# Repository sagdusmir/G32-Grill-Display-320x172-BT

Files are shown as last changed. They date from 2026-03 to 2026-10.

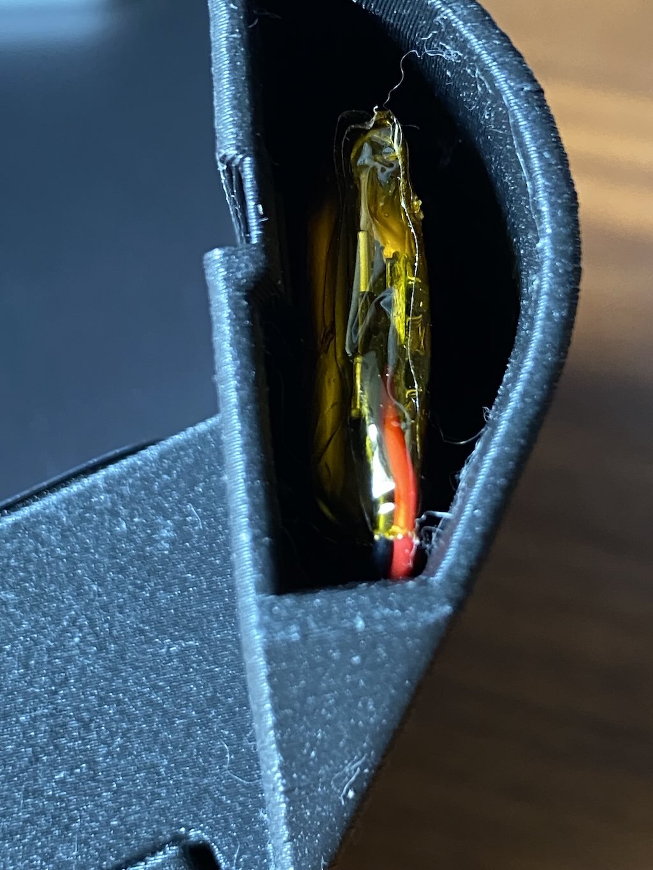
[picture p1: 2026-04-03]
misc/assembly/assembly_1_install_the_battery.jpeg

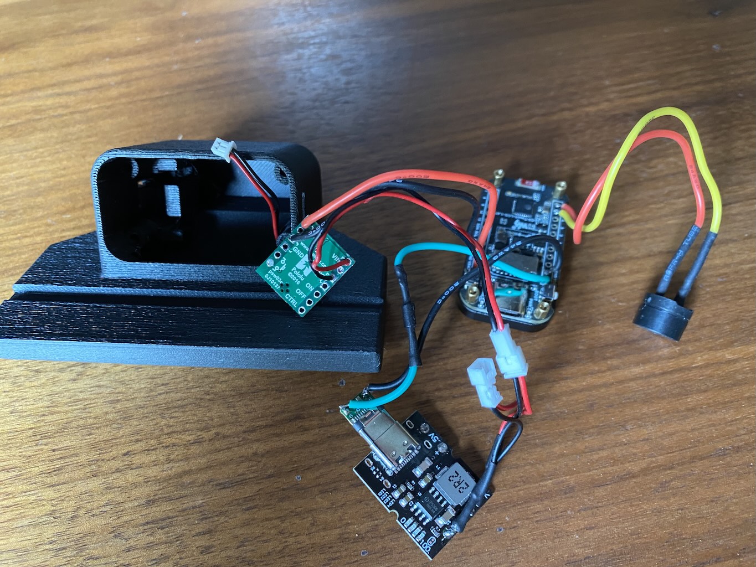
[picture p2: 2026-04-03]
misc/assembly/assembly_2_wiring_overview.jpeg

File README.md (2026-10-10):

# G32 Connected Grill Monitor and Display MINI








This repository is a stripped down version of https://github.com/sagdusmir/G32-Grill-Display-480x320-BTpref , but offers a better experience regarding power management.

Focus: **mobile, cloud-independent replacement** for the official Otto Wilde app / Grill Buddy — no cloud login, no Otto Wilde servers. Direct BLE connection to the grill (tested with firmware **v1.4.5**; older "v13" not compatible).

Teaser Gauges
Teaser Temperature Alarm
Teaser Info Page

Bare device during testing.<br>

# Table of Contents

1. [Features](#features)
   - [Implemented functionality](#implemented-functionality)  
   - [What is missing?](#what-is-missing)
   - [Limitations](#limitations)
3. [Hardware](#hardware)
   - [BOM](#bom)
   - [Component Details](#component-details)
   - [Wiring and Assembly](#wiring-and-assembly)
      - [Wiring](#wiring)
      - [Assembly](#assembly)
4. [Uploading the software to the ESP](#uploading-the-software-to-the-esp)
   - [Prebuilt firmware](#prebuilt-firmware)
   - [Compile from source](#compile-from-source)
5. [Troubleshooting](#troubleshooting)
6. [Acknowledgments](#acknowledgments)
7. [Disclaimer](#disclaimer)

## Features

### Implemented functionality

- **Automatic detection** of a near by G32 Connected
- Real-time temperatures for up to **4 grill zones** + **4 external probes**
- **Gas level** monitoring (if GasBuddy is installed)
- **Alarms** — visual indicator + optional buzzer for temperature limits and other alarms
- Touchscreen configuration
  - tap gauges to configure a temperature alarm (if the feature has not been disabled)
  - tap the rightmost status bar to see some other details
- Multiple **color schemes** (predefined + easy to add your own)
- **Connection & status icons** (BLE, WiFi, battery SOC)
- **Optional battery monitoring** the state of charge (SOC) of a connected battery can be displayed
- **Optional MEATER® integration** with **automatic detection** shows tip temperatures & battery SOC instead of G32 probes when connected. There is an alert if temperature specs are exceeded.
- **Optional Home Assistant** connectivity that exposes most of the measurements and allows confguring some settings of the device that can not be controlled using the UI on the device itself (min SOC level, min gas bottle level, color scheme, hide SOC, hide gas bottle level). At the moment HA will list about 38 entities for this device.

See [changelog.md](changelog.md).

### What is missing?
* **Meater 2 plus (aka PRO) support:** Meater 2 plus units are currently not supported
* **Gas Buddy:** calibration of a new gas bottle
* **G32 light:** setting the brightness level for turning on the light in the lid

### Limitations
* Everything that was mentioned above under [What is missing?](#what-is-missing)
* Volume level of the optional buzzer is a bit low.
* Meater probes can only connect to a single device at a time. However, this does not prevent using a Meater Block.

## Hardware
### BOM

| Component | Qty | Source | Costs |
|---|-----|---|---|
| ESP32 Dev Board | 1 | Amazon, AliExpress | ~15€ - 20€ |
| Battery | 1 | AliExpress | ~8€ - 12€ |
| Power Switch with Reverse Voltage Protection | 1 | somewhere online | ~5€ - 10€ |
| USB 5V 2A Boost Converter + Charger circuit  | 1 | AliExpress | ~2€ - 5€ |
| USB-C Connector | 1 | Amazon, eBay, AliExpress | ~2€ |
| 2 pin Wire Connectors | n | Amazon, eBay, AliExpress | ~2€ |
| Diode | 1 | eBay, somewhere online | ~1€ |
| Screws	 | 4	  | hardware store, eBay, Amazon, AliExpress | ~1€ |
| Buzzer	 | 1	  | Amazon, eBay, AliExpress | ~1€ |
| some wires (soft silicone wire recommended)  | n | AliExpress, Amazon, eBay | ~2€ |
| Kapton tape or electrical tape | ? | AliExpress, Amazon, eBay | ~0€ |
| Case | 1 | a friend with a 3d printer | a beer |
| USB-C Connection Cable | 1 | your existing collection of cables | ~0€ |

### Component Details

* __ESP32 Dev Board__<br>
  You need a "__Waveshare ESP32-C6-Touch-LCD-1.47__". It is equipped with an ESP32-C6, WiFi, Bluetooth, a 320x172 Pixel 1.47" touchscreen, and everything you need. No additional memory card required.

* __Battery__
  A 3.7V LiPo/Li-Ion Battery (1 cell) will power the ESP32 Dev Board. Because of space constraints I am going with a battery of type 702080  (7mm x 20mm x 80mm) with a capacity of 1500mAh.

* __Power Switch with Reverse Voltage Protection__<br>
  To minimize power draw, I am using a Pololu Mini Pushbutton Power Switch,Reverse Voltage Protection,LV (Pololu 2808) which should reduce power draw as much as possible. Unfortunately the module is a bit pricey.

* __5V 2A Boost Converter + Charger circuit__<br>
  I recommend using a cheap board that has an auto power-save feature. The one that I ultimately decided on goes under the name "Type-C USB 5V 2A Boost Converter Step-Up Power Module Lithium Battery Charging Protection Board LED Display USB Charger". The boost portion is actually not used because I wanted to keep it simple and have the SOC measurement working without adding another voltage divider for the voltage at the battery.
  Arduino PowerBoost 500C / 1000C modules seem to __NOT__ offer an automatic power-save feature, so this would completely drain the battery in a few days.
  <br>charger module

* __USB-C Connector__<br>
  To power the charger circuit it is very helpful to have a male USB-C plug breakout board to supply power. The solder pads / USB port on the backside of my pcb were only used for power output and I found no accessible pads to provide power directly to the charger circuit.
  <br>usb-c plug breakout board

* __2 pin Wire Connectors__<br>
  I used a few micro JST1.25 2pin connectors (male + female) to keep things modular. At least the battery should be easy do disconnect so you do not have to solder the wires while it is connected.

* __Diode__<br>
  A Schottky Diode with a low voltage drop of 0.3-0.4V (e.g. 1N5819) to separate the charging power path a bit from the rest because the documentation of most charge controllers will not be that detailed.

* __Buzzer__<br>
  A __passive__ piezo buzzer.<br>Configured pins are GPIO5 amd GPIO6. The buzzer should be rather small to fit inside tha case (e.g. ⌀13mm x 2.5mm or similar). The smaller the buzzer, the easier it is to mount the ESP32 Dev-Board in the enclosure. Even a "Universal Passive Buzzer 12085" (12mm x 8.5mm) will fit if you keep wires short.

* __Case__<br>
  There is a 3D model of a case in the `misc` folder. Using the case.m3f file is the easiest. If that does not work for you, you can give the two .stl files a try. I placed the main case with the bottom flat on the print bed. Enabled raft and manually added tree support from the bed to the underside of the power button, to the top of the usb-port cutout and in a straight vertical line in the middle of the back of the case so it does not tip over while printing. For the battery cover I placed the short straight edge on the build plate and manually added tree support to each untgerside of the clips and in a straight vertical line in the middle of the back to add some stability. I included some images in the repository that show where I painted support structures. __NOTE__: Do not try to operate the button before installing the Pololu. You will probably snap it if there is nothing to limit its way of travel.
  <br>Teaser Testing Case Design Render

### Wiring and Assembly

#### Wiring
Important:<br>
the Pololu push button will point to the outside of the case, so make sure to have the wires on the opposite side pointing
towards the other comonents.
Space is limited, so connect the USB-C breakout board to the charger as shown in the wiring draft and solder wires from the
top of the pcb horizontally to the right (for both: charger module and USB-C breakout board). If they point in any other direction, you will struggle to stuff everything into the case. 

- connect Pololu VOUT and GND to ESP32 BAT and GND
- connect Pololu VIN and GND in parallel with the battery to the battery pads of the charger module
- connect ESP32 VBUS and GND to the power input of the charger module with the Schottky diode as shown

The Pololu can be *carefully* slot into place (tight fit) with the wires pointing to the inside. The charger module with the installed USB plug should fit right inside the case (same orientation as in the wiring sketch). Place the piezo buzzer
on top and install the ESP32 Dev Board to close everything up. Use a bit of Kapton tape if exposed contacts might touch each other.
<br>wiring draft

#### Assembly
- drop the battery into place so the connector sticks out the display casing<br>
  assembly_1_install_the_battery

- component wiring overview for orientation<br>
  assembly_2_wiring_overview

- install the power switch by sliding it all the way down between the mounting posts (tight fit, and the top is intended to stick out a bit)<br>
  assembly_3_slide_pololu_down_the_case

- install the charger board with the USB-C breakout borad plugged in and push it down to make room for the buzzer and the wiring<br>
  assembly_4_orientation_of_the_charger_board
  assembly_5_push_charger_board_down_so_there_is_place_for_the_buzzer_on_top

- put the buzzer on top of the charger board and install the display (do not pinch the wires or trap any of them between the display and the mounting posts)<br>
  assembly_6_install_display_without_trapping_wires_below_the_mounting_posts
  Teaser Testing Case Design
  impression
  impression
  impression
  comparison
  alternative case design idea

## Uploading the software to the ESP

### Prebuilt firmware

Each [GitHub Release](https://github.com/sagdusmir/G32-Grill-Display-320x172-BT/releases/latest) includes compiled images with placeholder Wi-Fi, OTA, and Home Assistant values. The extra `.espbinpatch` suffix is the same firmware as a `.bin` — patch those secrets, then flash. Do not flash the download as-is.

| File | When to use |
|---|---|
| `*.factory.bin.espbinpatch` | First flash on a new or empty device (erases everything) |
| `*.ota.bin.espbinpatch` | Later updates if the device already works (keeps Wi-Fi and other saved settings) |

1. Download the matching file from the latest release.
2. Use the ESP Bin Patcher link in the release notes (preconfigured) in **Chrome or Edge**.
3. Choose the downloaded file on that page.
4. Fill in the replacements (Wi-Fi SSID, Wi-Fi password, OTA password, Home Assistant API key).
   For the API key, paste your Home Assistant / ESPHome `api.encryption.key` (the Base64 value) as **New**.
5. Click **Patch firmware**, connect the board via USB, then **Install patched firmware**.
   - Factory file: choose **Erase everything**.
   - OTA file: choose **Keep saved settings**.
6. You might need to power-cycle the device after flashing if the screen shows some artefacts.

### Compile from source

1. Install ESPHome CLI
   ```bash
   pip install esphome
   ```
2. Clone this repository and change directory into that folder
   ```bash
   git clone https://github.com/sagdusmir/G32-Grill-Display-320x172-BT.git && cd G32-Grill-Display-320x172-BT
   ```
3. Connect the ESP32-C6 1.47 Inch Display Development Board via USB
4. Compile and flash the software
   ```bash
   esphome run g32-display-mini.yaml
   ```
   You may be asked how the connection should be established.
5. You might need to reset the device after flashing to get the display to work (push the RST button).

## Troubleshooting

1. If compiling and flashing the ESP32 succeeds, but the screen is looking distorted afterwards, skimply turn the power off and on agaoin. Pressing the BOOT button in the device is not sufficient.

2. Starting with esphome 2026.4.0 the display driver had to be changed and the output on the display might look garbled at first. Disconnecting and reconnecting power should fix this issue.
   
3. During validation of the yaml file, you might see something like `[max_connections] is an invalid option for [esp32_ble]`. The "max_connections" option has been moved from "esp32_ble_tracker:" to "esp32_ble:". Both variants are included in the YAML and you need to switch to the other variant by adding / removing a comment (#). Do not mess up the indentation. This is caused by a breaking change in esphome.

4. If compiling and flashing the ESP32 succeeds, but the screen is looking distorted (the left portion is partially readable while the right portion shows mostly pixel noise"), simply look at the "dimensions" in the "display" section and swap the values for "width:" and "height:". This is caused by a breaking change in esphome.

5. If you get A LOT of strange syntax errors, try to clean up the configured build folder via
   ```bash
   esphome clean g32-display-mini.yaml
   ```

## Acknowledgments
This project would not have been possible without the work of the community. Special thanks go to:

[Esaracci](https://community.home-assistant.io/u/esaracci/) (using this hardware with esphome)

[Pulpyy](https://community.home-assistant.io/u/pulpyy) (using this hardware with esphome)

[JBecker32/G32-Display-480x320-BT](https://github.com/JBecker32/G32-Display-480x320-BT) (the original software project)

[fschwarz86/g32](https://github.com/fschwarz86/g32)

[tobsch/g32-investigations](https://github.com/tobsch/g32-investigations) (additional information about BLE and serial communication)

[ralmoe/g32-docker-client](https://github.com/ralmoe/g32-docker-client)

[MortenVinding/MEATER.yaml](https://gist.github.com/MortenVinding/a513c0094d0df41a4425612257b3cabc) (Meater® accuracy)

## Disclaimer
This is third-party software developed by the community and is not officially developed or supported by Otto Wilde GmbH. Use at your own risk.

__This project is provided for educational and experimental purposes only.__

All hardware designs, schematics, code, instructions, and documentation are offered AS IS without any warranty of any kind, express or implied.
YOU BUILD AND USE THIS AT YOUR OWN RISK.
The author(s) and any contributors are not responsible for any injury, death, property damage, fire, electrical shock, data loss, voided warranties, legal violations, or any other consequences — direct, indirect, incidental, or consequential — that may result from building, modifying, or using this project or any derivative work.
Always follow local electrical/safety/building codes.

If you're not experienced with mains voltage, high current, lithium batteries, lasers, moving parts, etc., consult a qualified professional before proceeding.
Proceed only if you accept full personal responsibility.

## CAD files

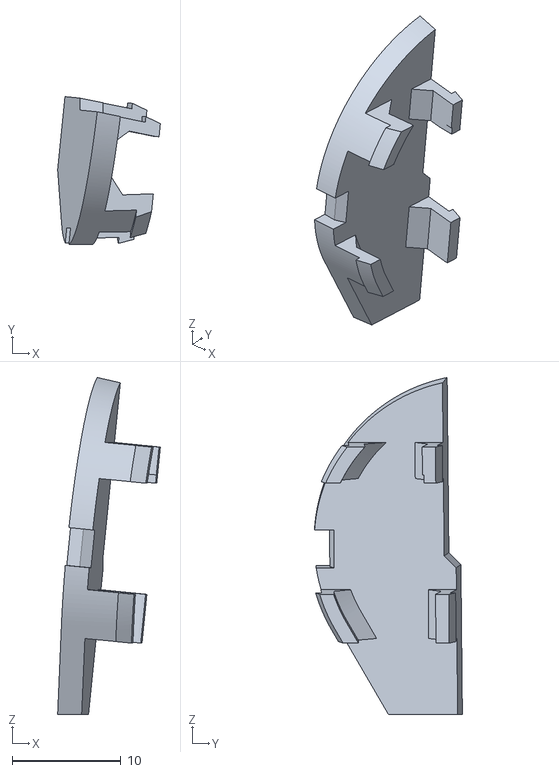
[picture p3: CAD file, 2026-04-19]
misc/case/case_battery_cover.stl
9.46 x 13.6 x 31.0

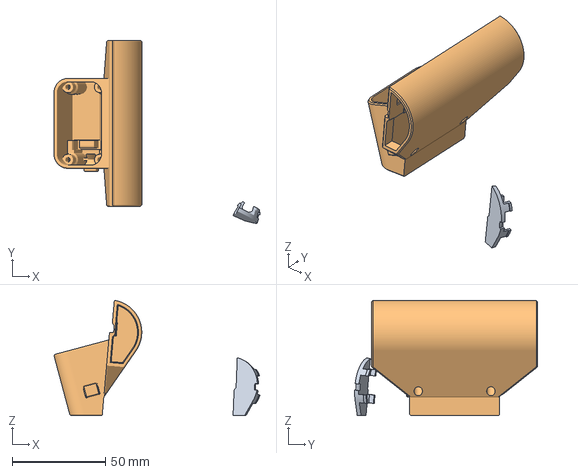
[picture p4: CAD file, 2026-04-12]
misc/case/case_and_battery_cover.3mf
110.6 x 98.2 x 61.9 mm
Battery Cover.stl
Main Body.stl

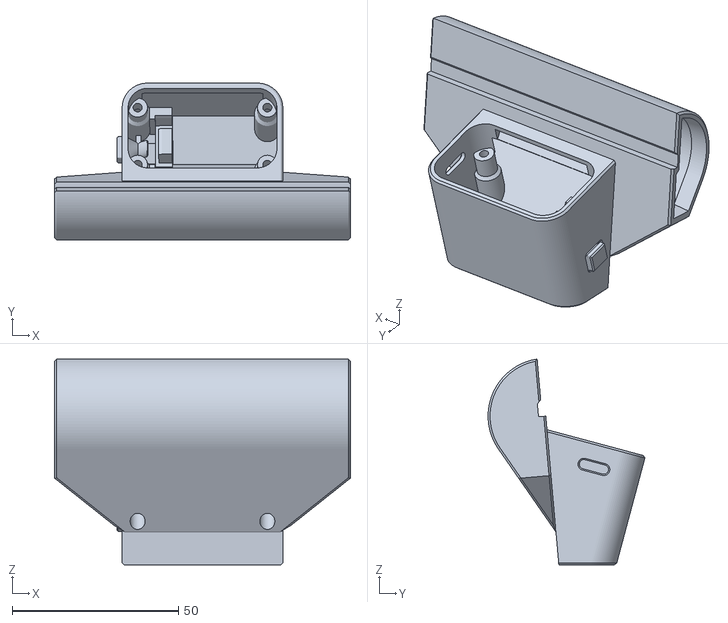
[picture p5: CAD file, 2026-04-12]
misc/case/case.stl
89.0 x 47.2 x 61.9

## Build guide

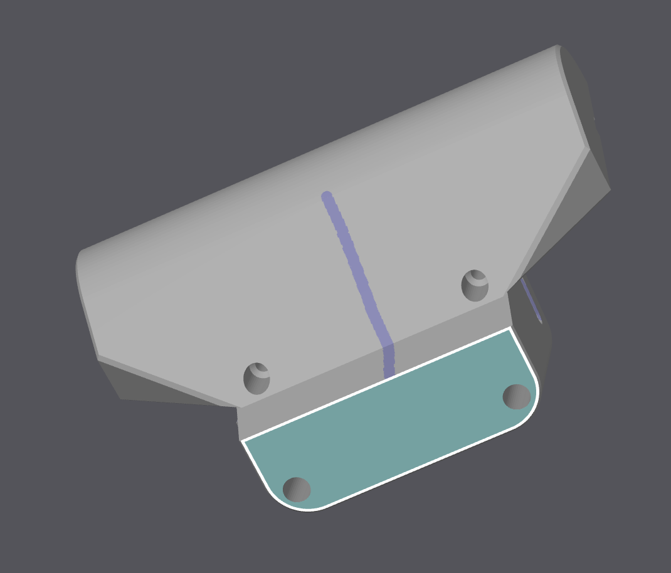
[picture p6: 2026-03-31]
misc/case/manual_tree_support_case_1.png

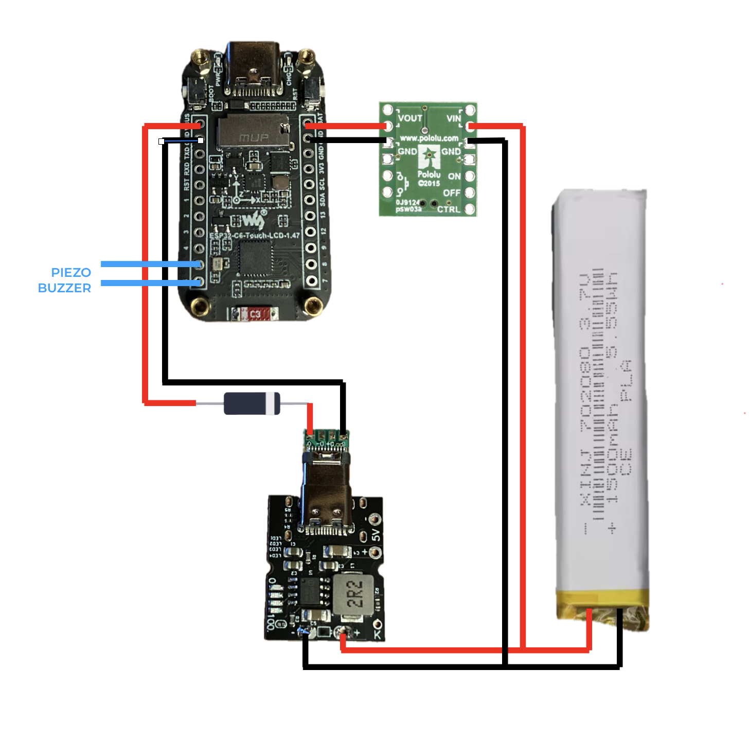
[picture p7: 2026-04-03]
misc/wiring_sketch.png

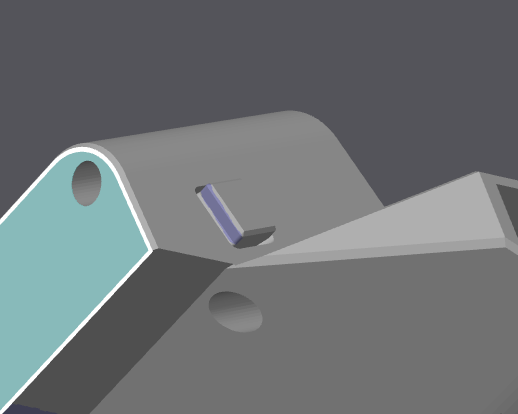
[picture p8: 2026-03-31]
misc/case/manual_tree_support_case_2.png

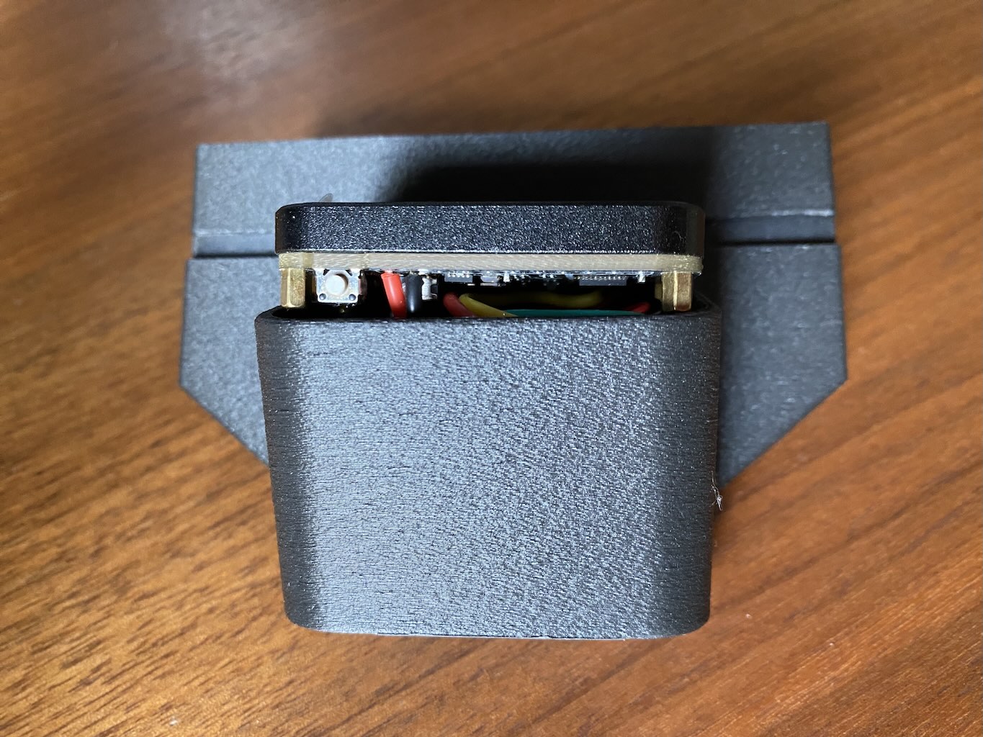
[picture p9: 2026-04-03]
misc/assembly/assembly_6_install_display_without_trapping_wires_below_the_mounting_posts.jpeg

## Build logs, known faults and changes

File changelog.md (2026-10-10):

# Changelog
* [2026-10-10] BTmini 1.2.0-beta
   - rewrite code for reading the BLE data frame
   - read additional BLE characteristics beyond the 32 bytes we get from the G32
   - expos additional values to HA
   - minor refinements of HA values
* [2026-10-03] BTmini 1.1.5
   - workaround for garbled screen after flashing
* [2026-09-17] BTmini 1.1.4-1
   - polishing release workflow
* [2026-09-17] BTmini 1.1.4

* [2026-09-13] BTmini 1.1.3
   - meater tip temperature reading now supports frozen steaks
* [2026-09-13] BTmini 1.1.2
   - updated for esphome 2026.8.x compatibility
* [2026-07-21] BTmini 1.1.1
   - minor fix: check for g32_firebox_open
* [2026-05-01] BTmini 1.1.0
   - refinement of temperature limits page by adding a +1 and -1 button next to the slider
* [2026-04-17] BTmini 1.0.6
   - add compatibility with esphome 2026.4.0
* [2026-04-12] BTmini 1.0.4
   - minor changes to the case model
   - no software changes
* [2026-04-06] BTmini 1.0.3
   - minor changes to the battery cover model
   - no software changes
* [2026-03-25] BTmini 1.0.2
   - show soc and gas level warning value on settings page
   - slightly improved color schemes
* [2026-03-25] BTmini 1.0.1
   - color scheme options for HA have now be moved to the top
   - color scheme preview on settings page (this will assist in fixing colors for the display of the dev-board)
* [2026-03-19] BTmini 1.0.0
   - disable HA backlight switch
   - enable some options through HA that were not accessible because of the missing settings page
* [2026-03-15] BTmini 0.2.2
   - change IP Address wording
   - define emty text for clickable status bar label to get rid of the fallback „Text“
* [2026-03-13] BTmini 0.2.1
   - no duplicated sounds on BLE events
* [2026-03-13] BTmini 0.2.0
   - add „details“ page that is accessible by clicking somewhere into the right status bar
   - display current IP address and numeric gasbuddy level
* [2026-03-07] BTmini 0.1.0
   - initial release and barely tested

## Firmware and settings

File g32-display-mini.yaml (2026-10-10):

substitutions:
  # # # # # # # # # # # # # # # # # # # # # # # # # # # # # # # # # # # # # # # # #
  # You will propably need to do changes only to the following lines (if at all): #
  # # # # # # # # # # # # # # # # # # # # # # # # # # # # # # # # # # # # # # # # #

  # Name of the ESPHome device (modify if you like, avoid special characters)
  name: g32-display-mini
  device_description: "Monitor an OW G32 grill "
  version: "BTmini 1.2.0-beta"

  # either pull values from secrets.yaml
  # or have it directly in this file
  wifi_ssid: !secret wifi_ssid
  wifi_password: !secret wifi_password
  # wifi_ssid: "INSERT_YOUR_WIFI_SSID"
  # wifi_password: "INSERT_YOUR_WIFI_PASSWORD"

  # Enter data of the newly created Home Assistant ESPHome device. Example:
  api_encryption_key: "YcM9Kcc+DRDHfISFcF8FlDN0WuanM1LJV3duK/PugZA="

  # over-the-air updates (ESPHome CLI or Home Assistant add-On)
  # Hint: if you changed this value on the device, you might have to alter
  # this value here to match it. esphome cli uses the value from the yaml for the ota update!
  ota_password: "8fdf9f656d36180bfba92d596c9e7db4"

  # color scheme
  SETTINGS_COLOR_SCHEME_IDX: "0"  # initially selected color scheme
  COLOR_SCHEMES: |
    //                  idx 100%      75%       50%       25%       <=25%    GOOD      BAD       LIGHT
    {                        
      {"white",         {0, 0xffffff, 0xdfdfdf, 0xbfbfbf, 0x808080, 0x808080, 0x8bff85, 0xff5757, 0xffff00}},
      {"amber",         {1, 0xffb900, 0xc08b00, 0x805d00, 0x392900, 0x392900, 0x58b100, 0xff5600, 0xffff00}},
      {"cyan",          {2, 0x68e2fb, 0x34acbf, 0x007582, 0x003c43, 0x003c43, 0x75fb8a, 0xea838d, 0xffff00}},
      {"night red",     {3, 0xff0059, 0xe0004f, 0xc00044, 0x80002e, 0x80002e, 0xff0059, 0xe4d300, 0xffff00}},
      {"green",         {4, 0x00ff00, 0x03d600, 0x058d00, 0x046f00, 0x046f00, 0x00ff00, 0xfe3a03, 0xffff00}},
      {"night blue",    {5, 0x1a00ff, 0x1700db, 0x1300b6, 0x0d007a, 0x0d007a, 0x00ff4d, 0xff0092, 0xffff00}},
      {"purple",        {6, 0xff00e4, 0xe000c8, 0xc000ac, 0x800073, 0x800073, 0x00ffb0, 0xff1100, 0xffff00}},
      {"yellow",        {7, 0xffda00, 0xc0a400, 0x806d00, 0x262000, 0x262000, 0x64dc00, 0xff5900, 0xffff00}},
      {"white (clean)", {8, 0xffffff, 0xdfdfdf, 0xbfbfbf, 0x808080, 0x000000, 0x8bff85, 0xff5757, 0xffff00}}
    }

  COLOR_SCHEME_OPTIONS:  # required for Home Assistant
    - "white"
    - "amber"
    - "cyan"
    - "night red"
    - "green"
    - "night blue"
    - "purple"
    - "yellow"
    - "white (clean)"

  FORCE_SHADOW_COLOR_TO_BLACK: 'false'  # standard: use COLOR_00 for shadows
  # FORCE_SHADOW_COLOR_TO_BLACK: 'true'  # alternative: symbol and text shadows should not be visible

  # max temperature for zones and sensors
  Zone_Max: "500"
  Sensor_Max: "100"

  # minimum gas tank level
  SETTINGS_HIDE_GAS_LEVEL: "false"
  SETTINGS_MIN_GAS_VALUE: "15"

  # battery SOC
  SETTINGS_HIDE_SOC: "false"
  SETTINGS_MIN_SOC_VALUE: "25"

  # interval for alarm sound
  Beeper_interval: "5s"

  # Meater protection alerts
  meater_tip_alert: '100'  # Specs: 100°C (original Meater: 100°C, 105°C (Meater PRO - not supported yet)
  meater_ambient_alert: '270'  # Specs: 275°C (original Meater), 550°C (Meater PRO - not supported yet)

  # sounds (in RTTTL syntax):
  G32_Connect_Sound: "pling2:d=16,o=6,b=140:e6,32p,d6"
  G32_Disconnect_Sound: "siren:d=8,o=5,b=100:d,e,d,e,d,e,d,e"
  MT_Connect_Sound: "Pling4:d=16,o=5,b=100:a5,32p,a6"
  MT_Disconnect_Sound: "plonk:d=16,o=5,b=100:a6,32p,a5"
  Wifi_Connect_Sound: "dadi:d=16,o=6,b=140:d6,32p,e6"
  Wifi_Disconnect_Sound: "siren:d=8,o=5,b=100:d,e,d,e,d,e,d,e"
  Zone_Limit_Alarm_Sound: "dadidadi:d=8,o=5,b=150:d,e,d,e,d,e,d,e"
  Sensor_Limit_Alarm_Sound: "didadida:d=8,o=5,b=150:e,d,e,d,e,d,e,d"
  New_MAC_Sound: "click:d=32,o=6,b=120:32c,32p"

  # D A N G E R  Z O N E! # # # # # # # # # # # # # # # # # # # # # # # # # # # # 
  # From here on, please only make changes if you know what you are doing and   #
  # have an idea of what you want to achieve. :)                                #
  # # # # # # # # # # # # # # # # # # # # # # # # # # # # # # # # # # # # # # # #

  g32_mac_address: 94:E6:86:00:00:00
  g32_service_uuid: dc0f41ea-b6ae-46a8-a19e-1a3bf4342bcb
  g32_characteristic_uuid_tx: 'dc0f41e2-b6ae-46a8-a19e-1a3bf4342bcb'
  # g32_characteristic_uuid_rx: 'dc0f41e1-b6ae-46a8-a19e-1a3bf4342bcb'  # from the original OW app
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

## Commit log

2026-02-18 update esp32: section
2026-02-23 add sensor_limits_page
2026-02-23 add first sensor gauge
2026-02-25 add remaining sensor gauges and meater UI elements
2026-02-25 update bat adc reading
2026-03-13 feature/details-page
    - add „details“ page that is accessible by clicking somewhere into the right status bar
    - display current IP address and numeric gasbuddy level
2026-03-13 no sounds for esp32_ble_tracker
2026-03-15 fix unwanted fallback „Text“ in the right status bar
    - change IP Address wording
    - define emty text for clickable status bar label to get rid of the fallback „Text“
    [g32-display-mini.yaml]
2026-03-19 feature/settings-via-home-assistant
    - disable HA backlight switch
    - enable some options that weren not accessible because of the missing settings page
    [g32-display-mini.yaml]
2026-03-23 Update charger circuit description in README.md
2026-03-23 Modify USB Boost Converter price in README
    Updated price range for USB 5V 2A Boost Converter.
2026-03-25 bugfix: fix color scheme options in HA and add a color preview on settings page
    the color scheme preview will assist in fixing wierd color representations of the used display
    [g32-display-mini.yaml]
2026-03-25 improvements on color scheme options
    - color scheme options for HA have now be movet to the top
    - color scheme preview on settings page (this will assist in fixxing colors for the display of the dev-board)
    [g32-display-mini.yaml]
2026-03-26 fix: increase line height on info page
    [g32-display-mini.yaml]
2026-03-27 Add Testing Case Design teaser image to README
    Added an image for the Testing Case Design to the README.
2026-03-28 Add Testing Case Design Render image to README
2026-03-30 Fix typo in USB-C connector description
2026-03-31 add wiring instructions and 3d model of a case
    [case.3mf, case.stl, case_battery_cover.stl]
2026-03-31 Fix grammar in wire connectors section
    Corrected grammatical errors in the description of wire connectors.
2026-04-01 add chamfer to model
    [case.3mf, case.stl]
2026-04-01 Fix wording in README for wiring instructions
    Corrected wording for clarity regarding wire connections and fitting components.
2026-04-01 Replace wiring draft image in README
    Updated wiring image in the README file.
2026-04-03 add assembly images
2026-04-03 add warning about the push button
2026-04-03 Revise Wiring section to include Assembly details
    Updated section titles for clarity and added assembly instructions.
2026-04-04 Refine power switch installation instructions and format
    Updated descriptions for power switch installation and adjusted item formatting.
2026-04-04 Update README with additional assembly images
    Added new images to the assembly instructions in the README.
2026-04-06 fixed stl orientation
    [case.stl, case_battery_cover.stl]
2026-04-06 increased clip stability for battery cover
    - minor changes to the battery cover model
    [case.3mf, case_and_battery_cover.3mf, case_battery_cover.stl]
2026-04-07 Clarify power-save feature of PowerBoost modules
2026-04-07 Update README with improved alarm descriptions
    Clarified alarm descriptions and added details for temperature alarm configuration.
2026-04-12 refined button strength
    [case.stl, case_and_battery_cover.3mf]
2026-04-19 fix default orientation
    [case_battery_cover.stl]
2026-04-20 fix: add missing label in HA to Meater Battery SOC readings
    [g32-display-mini.yaml]
2026-05-01 fix label width so the value does fit
    [g32-display-mini.yaml]
2026-05-01 feature/ux-of-temperature-limits-page
    - refinemanet of temperature limits page by adding a +1 and -1 button next to the slider
2026-05-01 Recommend soft silicone wire for 'some wires'
    Updated the description of 'some wires' to recommend soft silicone wire.
2026-05-01 Update README to enhance repository description
    Clarified the repository's purpose and improved the description regarding power management.
2026-06-14 nop - tesing new esphome WAVESHARE-ESP32-C6-LCD-1.47 support was a miss
2026-06-27 Update USB-C connector description for clarity
    Clarified the description of the USB-C connector usage in the README.
2026-07-21 bugfix/ble-client-data-condition
    - minor fix: check for g32_firebox_open
    [g32-display-mini.yaml]
2026-09-13 bugfix/esphome_2026.8.2
    - updated for esphome 2026.8.x compaitibilty
    [g32-display-mini.yaml]
2026-09-13 bugfix/meater-negative-temperatures
    - meater tip temperature reading now supports frozen steaks
    [g32-display-mini.yaml]
2026-09-13 fix font file urls
    [g32-display-mini.yaml]
2026-09-17 update release workflow to attach compiled firmware with placeholders to the release
2026-10-10 feature/improved-ble-dataframe-parsing
    - rewrite code for reading the BLE data frame
    - read additional BLE characteristics beyond the 32 bytes we get from the G32
    - expos additional values to HA
    - minor refinements of HA values
2026-10-25 Update README to remove power-cycle note
    Removed note about power-cycling the device after flashing.
2026-10-26 Clarify hardware differences for Waveshare ESP32-C6
    Added a note about the non-touch version of the Waveshare ESP32-C6-Touch-LCD-1.47 hardware.
2026-10-31 nicer wiring diagram
2026-10-31 Replace wiring draft image with wiring sketch image
    Updated wiring image reference in the README.
2026-10-31 even nicer wiring diagram
2026-10-31 Replace wiring sketch image in README
    Updated wiring sketch image link in README.
